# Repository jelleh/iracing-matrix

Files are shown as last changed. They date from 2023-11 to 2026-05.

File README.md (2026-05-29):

# iRacing Matrix

## Description

Arduino based low latency RPM and gear indicator for the iRacing motorsport simulator.  

## Overview

The goal is to build a plug-and-race, easy to setup, low latency gear and RPM indicator for iRacing.  

It will display your current speed and RPM on the 7 segment display  
On the left led strip you will see the braking percentage,  
and the right strip displays the RPM percentage between 70% and 100%  
The RPM led strip will blink quickly when the RPM percentage is above 99%  
  
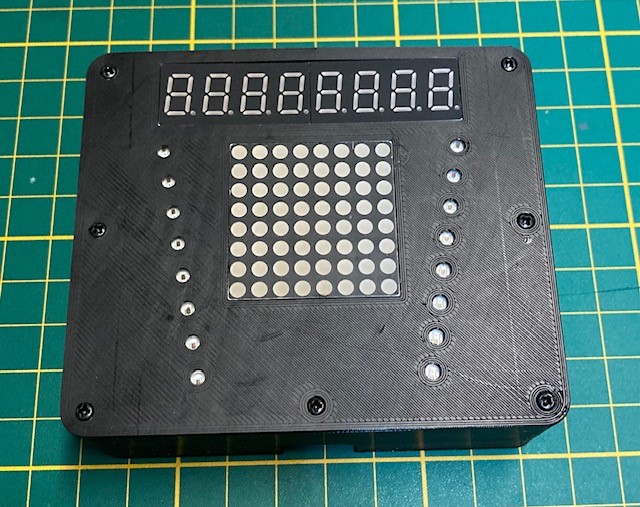
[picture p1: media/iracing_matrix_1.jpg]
  
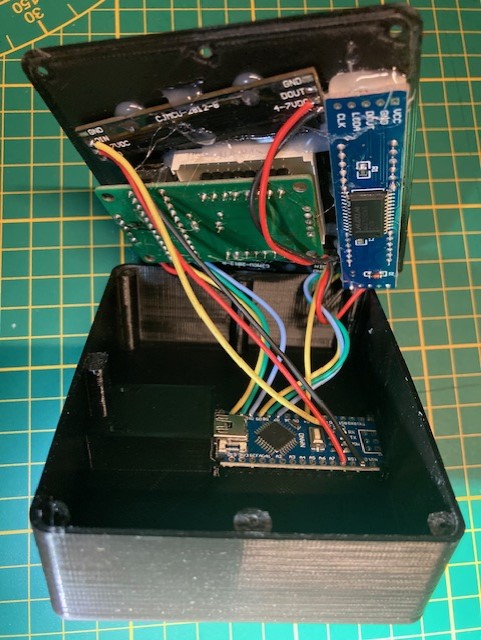
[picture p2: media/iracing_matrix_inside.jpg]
Housing inside
  
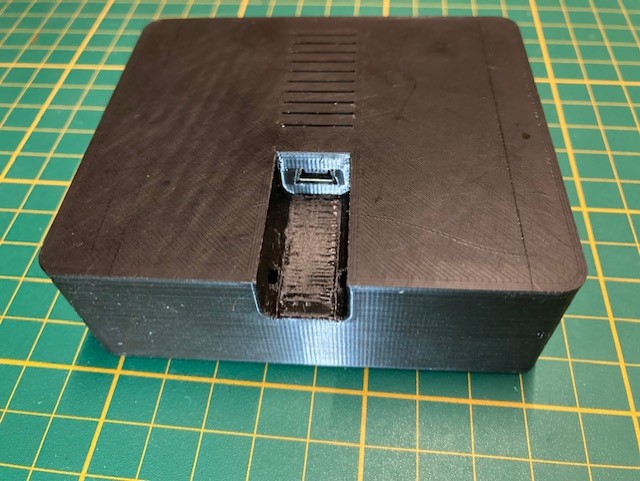
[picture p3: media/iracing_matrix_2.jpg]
  
  
>STL files included and available on [Thingiverse](https://www.thingiverse.com/thing:6325240)

*Running the executable*  
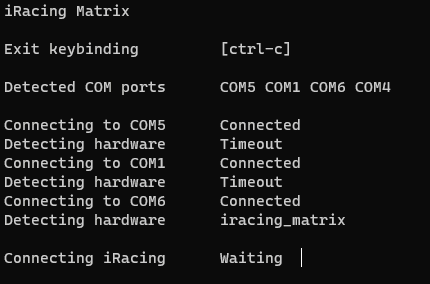
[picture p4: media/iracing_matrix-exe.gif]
Executable


*Calibrate the RPM indicator and drive*  
Calibrate RPM  

*Fast cycle through gears*  
Race  

## Components

To build iRacing Matrix, you will need the following components:  
>You can buy all the components on [AliExpress](https://s.click.aliexpress.com/e/_DcGzUr5).  

1. **Microcontroller Board:**
   - Description: The brain is an Arduino board with mini usb, the Arduino Nano will fit the housing.
   - Example: [Arduino Nano Atmega328 mini usb](https://s.click.aliexpress.com/e/_DkWYniB)

1. **Housing:**
   - Description: The provided housing is build to fit an Arduino nano, feel free to build your own housing.
   - Example: Available in the housing directory or at [Thingiverse](https://www.thingiverse.com/thing:6325240)

2. **Gear indicator:**
   - Description: Gear indicator is a MAX7219 Dot Led Matrix Module
   - Example: [MAX7219 Dot Led Matrix Module](https://s.click.aliexpress.com/e/_Dli12on)

3. **RPM and brake indicator:**
   - Description: RPM and brake indicator are two 8 channel WS2812 505 RGB LED strips
   - Example: [WS2812 5050 8 channel RGB LED](https://s.click.aliexpress.com/e/_DlZAn4x)

4. **Display:**
   - Description: MAX7219 based 8 digits 7 segments display
   - Example: [MAX7219 8 digits 7 segments](https://s.click.aliexpress.com/e/_Dewr8uB)

6. **Screws, Wires and hot glue:**
   - Description: Used for assembling and connecting components.
   - Example:
     - [Silicone 28AWG wires](https://s.click.aliexpress.com/e/_Dm14y7V)
     - [M1.7x6 screws](https://s.click.aliexpress.com/e/_DB2Fljt)
     - [Hot glue gun](https://s.click.aliexpress.com/e/_DlX8qxz)

## Schematic

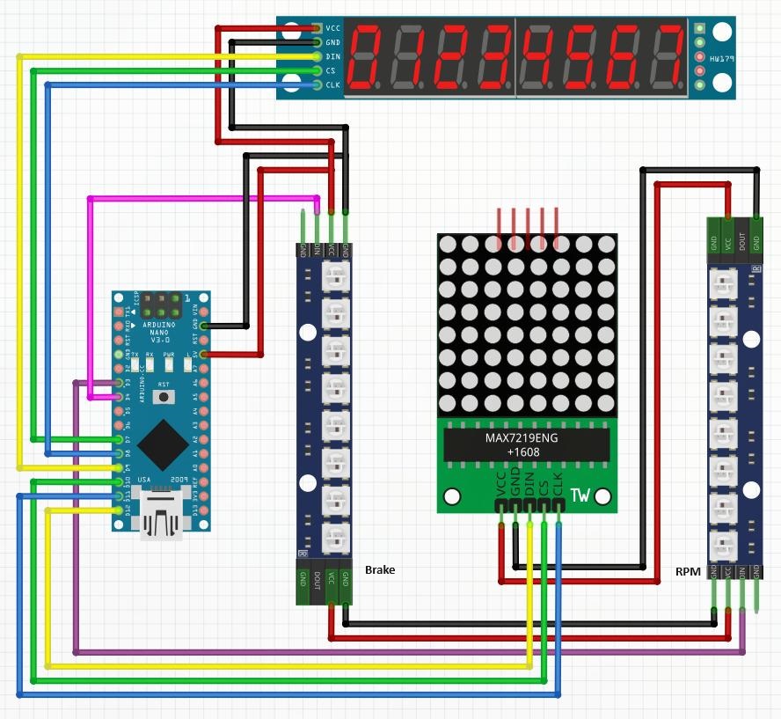
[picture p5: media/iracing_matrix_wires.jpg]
Wires


## Housing

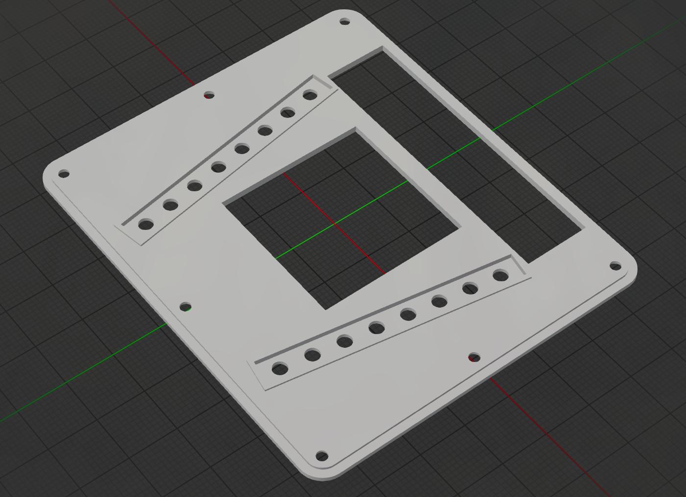
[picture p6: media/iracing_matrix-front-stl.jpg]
Housing front

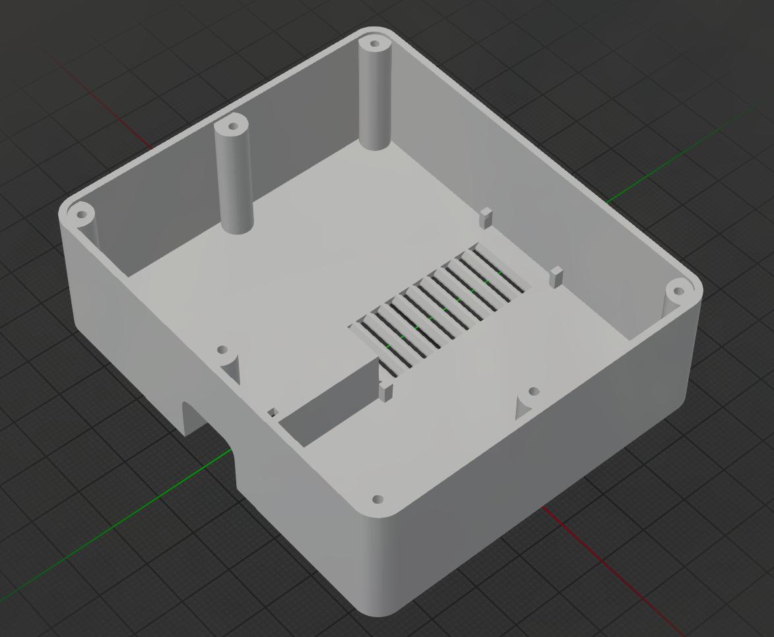
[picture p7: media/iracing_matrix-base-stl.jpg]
Housing base
  
Download on [Thingiverse](https://www.thingiverse.com/thing:6325240/files)  

## Building from source

Requires [MinGW-w64](https://www.mingw-w64.org/) (cross-compile on Linux) or Visual Studio (on Windows).

**VS Code (Linux):** open the repo, then **Terminal → Run Build Task** — this runs the MinGW-w64 cross-compiler and outputs `iracing_matrix.exe`.

**CLI (Linux):**
```bash
cd program/iracing_matrix
x86_64-w64-mingw32-g++ -o iracing_matrix.exe iracing_matrix.cpp irsdk/irsdk_client.cpp irsdk/irsdk_utils.cpp irsdk/yaml_parser.cpp irsdk/irsdk_ir2ad/serial.cpp -I irsdk -I irsdk/irsdk_ir2ad -lwinmm -static -O2
```

**Visual Studio (Windows):** open `program/iracing_matrix.sln` and build.

## Executable

Download the prebuild [iracing_matrix.exe](https://github.com/jelleh/iracing-matrix/releases/download/v1.0/iracing_matrix.exe), or build it from source with Visual Studio.  
The executable will interact with the iracing API, and send updates over the COM port to the Arduino.  
When started, it will scan all the available COM ports for the iRacing Matrix,  
You can provide a fixed COM in the paramaters for faster startup.  
> iracing_matrix.exe [COM port]  
> e.g.: *iracing_matrix.exe 5*  

## Calibration
The RPM indicator needs to be calibrated once per session.  
When calibration is needed, iRacing Matrix will display *fll thr* on the 7-segment digits.  
Completely stop the car, enter neutral gear, and full throtle.  

## Getting Started

Follow these steps to build and use iRacing Matrix:

1. **Assemble iRacing Matrix:**
   - Connect the microcontroller to your computer and upload the provided Arduino code [iracing_matrix.ino](sketch/iracing_matrix/iracing_matrix.ino).
   - Remove the sides (mounting holes) from the 7-segment display with a hacksaw, otherwise it will not fit. (see pictures)
   - Follow the circuit diagram to connect the components to the microcontroller.
   - Download the [stl files](./housing), and print the housing.
   - Glue the components to the front part of the housing with some hot glue.
   - Secure the Arduino nano in the housing, first put the mini usb in the opening, and push the Arduino all the way down.
   - Attach the front and base toghther with seven M1.7x6 screws.

2. **Connect:**
   - Connect the Arduino via usb to you computer.

3. **Run:**
   - Run [iracing_matrix.exe](https://github.com/jelleh/iracing-matrix/releases/download/v1.0/iracing_matrix.exe) on your iRacing pc. It will automiticly scan the COM ports for iRacing Matrix.

4. **Calibrate:**
   - Enter an iRacing session, and full throtle in netrual gear to calibrate the RPM indicator.

5. **Race:**
   - Exit the pit, and race.

## License

This project is licensed under the [BSD-3-Clause](LICENSE).

---

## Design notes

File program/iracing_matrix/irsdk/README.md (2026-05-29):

irsdk
=====

Clone of the offical iRacing SDK C++ library

====

The following is from the iRacing members forum: http://members.iracing.com/jforum/posts/list/1470675.page

Welcome to the new iRacing SDK, this api replaces the original iRacing Telemetry API with a cleaner implementation that supports multiple clients and an expanded list of functions. 

history: 
2011/04/27 - initial release 

2011/05/03 - Maintenance update 
- Fixed a conflict between Windows UAC and live telemetry, applications will need to be recompiled to continue working. 
- Fixed a bug in irsdk_broadcastMsg() that could cause the caller to hang indefinitely. 
- Telemetry now properly output from a replay 
- Removed the CarIdxThrottlePct, CarIdxBrakePct, and CarIdxClutchPct variables. 
- Fixed a bug that caused camera data to be erratic when pausing the simulator. 
- Added a small sample demonstrating how to read in an ibt file and convert it to a csv file. 

2011/05/06 - Maintenance update 
- Fixed a bug in the YAML parser that would not parse numbers greater than 9 in array entries {} 
- Initial stub of a C# port, probably not worth looking at. 

2013/01/15 - Maintenance update 
- Added new remote call 'irsdk_BroadcastReloadTextures' to trigger a reload of custom car textures. 

2013/07/22 - Maintenance update 
- Added new remote call 'irsdk_BroadcastChatComand' to help automate chat commands. 
- Added new remote call 'irsdk_BroadcastPitCommand' to allow custom manipulation of pit stop settings. 

2014/04/23 - Maintenance update
- Added new remote call 'irsdk_BroadcastTelemCommand' to allow toggling on/off of disk based telemetry 

2015/09/23 - Maintenance update
- Add new telemetry defines to irsdk_defines.h

2016/04/19 - Maintenance update
- New irsdkDiskClient helper class to simplify reading disk based .ibt files
- New irsdk_ffbforce demo that uses above class to monitor force feedback steering torque

2016/12/06 - Maintenance update
- Add support for 360 Hz telemetry
- New csvt2ibt project that converts csv text files to .ibt files 

2017/04/14 - Maintenance update
- clean up build scripts for VC2012 compatibility

2017/04/21 - Maintenance update
- improve csv2ibt so it can import csv files produced by writetest 

2019/01/26 - Maintenance update
- Update to SDK Version 1.12 and 
- Update of Windows SDK and VC platform toolset

2020/12/31 - Maintenance update
- Update of project files to VS2019

2021/05/21 - Maintenance update, added message support for control over video recording and screenshots.  

2024/03/04 - New rain defines, new .ibt irsdkDiskWriter class.  

2024/03/06 - New rain defines  

2024/03/18 - New tire compound change enum

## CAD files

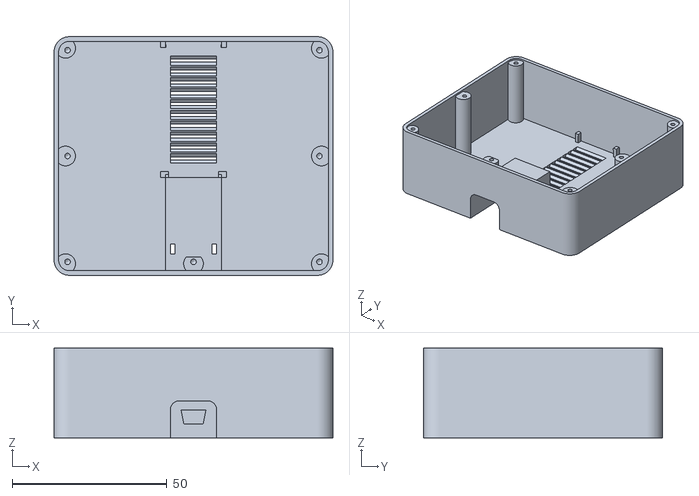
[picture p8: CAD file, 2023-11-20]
housing/iracing_matrix-base.stl
90.0 x 77.0 x 29.0

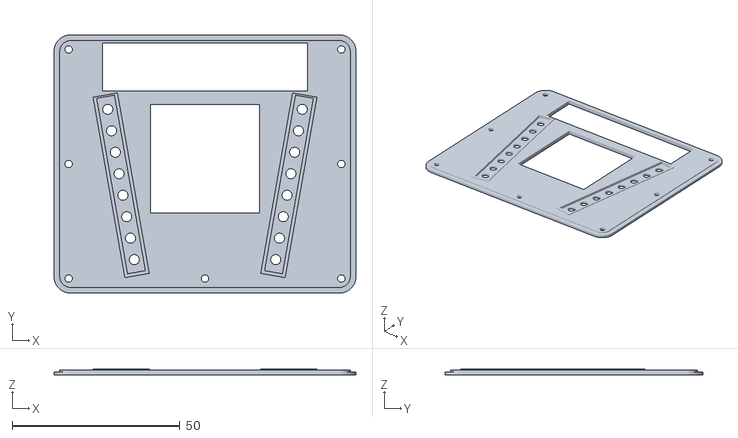
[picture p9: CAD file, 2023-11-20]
housing/iracing_matrix-front.stl
90.0 x 77.0 x 1.90

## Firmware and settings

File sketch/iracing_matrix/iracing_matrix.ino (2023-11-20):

/*
# Copyright (c) 2023 Jelle Hennevelt <jelle_AT_hennevelt_DOT_nl>
#
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
# 3. Neither the name of the copyright holder nor the names of its
# contributors may be used to endorse or promote products derived from this
# software without specific prior written permission.
#
# THIS SOFTWARE IS PROVIDED BY THE COPYRIGHT HOLDERS AND CONTRIBUTORS "AS
# IS" AND ANY EXPRESS OR IMPLIED WARRANTIES, INCLUDING, BUT NOT LIMITED TO,
# THE IMPLIED WARRANTIES OF MERCHANTABILITY AND FITNESS FOR A PARTICULAR
# PURPOSE ARE DISCLAIMED. IN NO EVENT SHALL THE COPYRIGHT HOLDER OR
# CONTRIBUTORS BE LIABLE FOR ANY DIRECT, INDIRECT, INCIDENTAL, SPECIAL,
# EXEMPLARY, OR CONSEQUENTIAL DAMAGES (INCLUDING, BUT NOT LIMITED TO,
# PROCUREMENT OF SUBSTITUTE GOODS OR SERVICES; LOSS OF USE, DATA, OR PROFITS;
# OR BUSINESS INTERRUPTION) HOWEVER CAUSED AND ON ANY THEORY OF LIABILITY,
# WHETHER IN CONTRACT, STRICT LIABILITY, OR TORT (INCLUDING NEGLIGENCE OR
# OTHERWISE) ARISING IN ANY WAY OUT OF THE USE OF THIS SOFTWARE,
# EVEN IF ADVISED OF THE POSSIBILITY OF SUCH DAMAGE.

# SPDX-License-Identifier: BSD-3-Clause
*/

#include "LedControl.h"
#include <Adafruit_NeoPixel.h>

// LED Matrix pins (DIN, CLK, LOAD/CS, MaxID)
// pin 12 is connected to DIN
// pin 11 is connected to CLK
// pin 10 is connected to LOAD/CS
LedControl lcMatrix=LedControl(12,11,10,1);

// pin 9 is connected to DIN
// pin 8 is connected to CLK
// pin 7 is connected to LOAD/CS
LedControl lcDigit=LedControl(9,8,7,1);

#define stripRpmPIN 3
#define stripBrakePIN 4
Adafruit_NeoPixel stripRpm = Adafruit_NeoPixel(8, stripRpmPIN, NEO_GRB + NEO_KHZ800);
Adafruit_NeoPixel stripBrake = Adafruit_NeoPixel(8, stripBrakePIN, NEO_GRB + NEO_KHZ800);


int maxRPM=0;
int lastRPM=0;
int lastGEAR=0;
//int rnd=0;

float lastSPEED=0;
float lastBRAKE=0;

String myString;
String type;

bool startRead=false;
bool stopRead=false;
byte matrixDC[8] = { B10000001,B01000010,B00100100,B00011000,B00011000,B00100100,B01000010,B10000001 };
byte matrixC[8] = { B00111100,B01100010,B01100000,B01100000,B01100000,B01100000,B01100010,B00111100 };
byte matrixR[8] = { B00111100,B01100110,B01100110,B01100100,B01111000,B01111000,B01101100,B01100110 };
byte matrixN[8] = { B01100110,B01100110,B01110110,B01111110,B01101110,B01100110,B01100110,B01100110 };
byte matrix1[8] = { B00011000,B00111000,B00011000,B00011000,B00011000,B00011000,B00011000,B01111110 };
byte matrix2[8] = { B00111100,B01100110,B00000110,B00001100,B00011000,B00110000,B01111110,B01111110 };
byte matrix3[8] = { B00111100,B01100110,B00000110,B00001100,B00001100,B00000110,B01100110,B00111100 };
byte matrix4[8] = { B00000110,B00001110,B00010110,B00100110,B01100110,B01111111,B00000110,B00000110 };
byte matrix5[8] = { B01111110,B01100000,B01100000,B01111100,B00000110,B00000110,B01100110,B00111100 };
byte matrix6[8] = { B00111100,B01100110,B01100000,B01111100,B01111110,B01100110,B01100110,B00111100 };
byte matrix7[8] = { B01111110,B01000110,B00000110,B00001100,B00001100,B00011000,B00011000,B00011000 };
byte matrix8[8] = { B00111100,B01100110,B01100110,B01111110,B01111110,B01100110,B01100110,B00111100 };
int row;

uint32_t rpmGREEN = stripRpm.Color(128, 255, 0);
uint32_t rpmYELLOW = stripRpm.Color(255, 166, 0);
uint32_t rpmRED = stripRpm.Color(255, 0, 0);
uint32_t rpmOFF = stripRpm.Color(0, 0, 0);
uint32_t rpmBlinkMillis = millis();
uint16_t rpmBlinkDelay = 50;

uint32_t brakeGREEN = stripRpm.Color(128, 255, 0);
uint32_t brakeYELLOW = stripRpm.Color(255, 166, 0);
uint32_t brakeRED = stripRpm.Color(255, 0, 0);
uint32_t brakeOFF = stripRpm.Color(0, 0, 0);

uint32_t dataRXmillis = millis();
uint16_t dataRXth = 1000;
uint32_t dataTXmillis = millis();

bool dataRX = false;

uint8_t toggle=0;


void setup()
{
  Serial.begin(115200);
  myString.reserve(200);

  //RPM Strip
  stripRpm.begin();
  stripRpm.setBrightness(20);
  for(int i=0; i<stripRpm.numPixels(); i++) {
    stripRpm.setPixelColor(i, rpmOFF);
  }
  stripRpm.show();

  //Brake Strip
  stripBrake.begin();
  stripBrake.setBrightness(20);
  for(int i=0; i<stripBrake.numPixels(); i++) {
    stripBrake.setPixelColor(i, brakeOFF);
  }
  stripBrake.show();

  //Gear Matrix
  lcMatrix.shutdown(0,false);// enables display
  lcMatrix.setIntensity(0,5);// sets brightness (0~15 possible values)
  lcMatrix.clearDisplay(0);// clear screen

  //RPM/SPEED Digits
  lcDigit.shutdown(0,false);// enables display
  lcDigit.setIntensity(0,5);// sets brightness (0~15 possible values)
  lcDigit.clearDisplay(0);// clear screen
}


void resetRPM()
{
  lcDigit.setRow(0,7,0x47);
  lcDigit.setRow(0,6,0x1c);
  lcDigit.setRow(0,5,0x0E);
  lcDigit.setRow(0,4,0x0E);
  lcDigit.setChar(0,3,' ',false);
  lcDigit.setRow(0,2,0x0F);
  lcDigit.setRow(0,1,0x17);
  lcDigit.setRow(0,0,0x05);

  //lcDigit.setChar(0,7,'f',false);
  //lcDigit.setRow(0,6,0x1c);
  //lcDigit.setChar(0,5,'l',false);
  //lcDigit.setChar(0,4,'l',false);
  //lcDigit.setChar(0,3,' ',false);
  //lcDigit.setRow(0,2,0x05);
  //lcDigit.setChar(0,1,'p',false);
  //lcDigit.setRow(0,0,0x15);
}


void lcdReady(bool sim=false)
{
  if(sim){
    lcDigit.setRow(0,7,0x05);
    lcDigit.setRow(0,6,0x3D);
    lcDigit.setRow(0,5,0x3B);
    lcDigit.setChar(0,4,' ',false);
    lcDigit.setChar(0,3,' ',false);
    lcDigit.setRow(0,2,0x05);
    lcDigit.setRow(0,1,0x3D);
    lcDigit.setRow(0,0,0x3B);  
  } else {
    lcDigit.setRow(0,7,0x05);
    lcDigit.setRow(0,6,0x3D);
    lcDigit.setRow(0,5,0x3B);
    lcDigit.setChar(0,4,' ',false);
    lcDigit.setChar(0,3,' ',false);
    lcDigit.setChar(0,2,' ',false);
    lcDigit.setChar(0,1,' ',false);
    lcDigit.setChar(0,0,' ',false);
  }
}


void rpmDigit(int value=0)
{
  int ones;
  int tens;
  int hundreds;
  int thousands;

  if(value < 10000){
    ones=value%10;
    value=value/10;
    tens=value%10;
    value=value/10;
    hundreds=value%10;
    value=value/10;
    thousands=value;

    lcDigit.setDigit(0,3,(byte)thousands,false);
    lcDigit.setDigit(0,2,(byte)hundreds,false);
    lcDigit.setDigit(0,1,(byte)tens,false);
    lcDigit.setDigit(0,0,(byte)ones,false);
  } 
  else{
    lcDigit.setDigit(0,3,(byte)9,false);
    lcDigit.setDigit(0,2,(byte)9,false);
    lcDigit.setDigit(0,1,(byte)9,false);
    lcDigit.setDigit(0,0,(byte)9,false);
  }
}


void speedDigit(int value=0)
{
  int ones;
  int tens;
  int hundreds;

  if(value < 1000){
    ones=value%10;
    value=value/10;
    tens=value%10;
    value=value/10;
    hundreds=value%10;
    
    lcDigit.setDigit(0,7,(byte)hundreds,false);
    lcDigit.setDigit(0,6,(byte)tens,false);
    lcDigit.setDigit(0,5,(byte)ones,false);
    lcDigit.setChar(0,4,' ',false);
  } 
  else{
    lcDigit.setDigit(0,7,(byte)9,false);
    lcDigit.setDigit(0,6,(byte)9,false);
    lcDigit.setDigit(0,5,(byte)9,false);
    lcDigit.setChar(0,4,' ',false);
  }
}


void gearMatrix(int value=0)
{         
  switch(value){
    //R
    case -1:
      row = 7;
      for (int column = 0; column < 8; column++) {
        lcMatrix.setColumn(0, column, matrixR[row]);
        row--;
      }
      break;

    //N  
    case 0:
      row = 7;
      for (int column = 0; column < 8; column++) {
        lcMatrix.setColumn(0, column, matrixN[row]);
        row--;
      }
      break;

    //1
    case 1:
      row = 7;
      for (int column = 0; column < 8; column++) {
        lcMatrix.setColumn(0, column, matrix1[row]);
        row--;
      }
      break;

    //2  
    case 2:
      row = 7;
      for (int column = 0; column < 8; column++) {
        lcMatrix.setColumn(0, column, matrix2[row]);
        row--;
      }
      break;

    //3  
    case 3:
      row = 7;
      for (int column = 0; column < 8; column++) {
        lcMatrix.setColumn(0, column, matrix3[row]);
        row--;
      }
      break;

    //4  
    case 4:
      row = 7;
      for (int column = 0; column < 8; column++) {
        lcMatrix.setColumn(0, column, matrix4[row]);
        row--;
      }
      break;

    //5  
    case 5:
      row = 7;
      for (int column = 0; column < 8; column++) {
        lcMatrix.setColumn(0, column, matrix5[row]);
        row--;
      }
      break;

    //6
    case 6:
      row = 7;
      for (int column = 0; column < 8; column++) {
        lcMatrix.setColumn(0, column, matrix6[row]);
        row--;
      }
      break;

    //7
    case 7:
      row = 7;
      for (int column = 0; column < 8; column++) {
        lcMatrix.setColumn(0, column, matrix7[row]);
        row--;
      }         
      break;

    //8
    case 8:
      row = 7;
      for (int column = 0; column < 8; column++) {
        lcMatrix.setColumn(0, column, matrix8[row]);
        row--;
      }    
      break;

    //C
    case 98:
      row = 7;
      for (int column = 0; column < 8; column++) {
        lcMatrix.setColumn(0, column, matrixC[row]);
        row--;
      }
      break;

    //X
    case 99:
      row = 7;
      for (int column = 0; column < 8; column++) {
        lcMatrix.setColumn(0, column, matrixDC[row]);
        row--;
      }
      break;
  }
}

void rpmStrip(int value=0, int brightness=25)
{
  if (brightness < 16){ brightness = 16; }
  if (brightness > 255){ brightness = 255; }

  if (value == -1){
    toggle = ~toggle;    
    if (toggle)
    {
      stripRpm.setBrightness(brightness);
      //for(int i=0; i<stripRpm.numPixels(); i++) {
      for(int i=stripRpm.numPixels(); i>=0; i--) {
        stripRpm.setPixelColor(i, rpmRED);
      }
      stripRpm.show();
    }else{
      stripRpm.setBrightness(brightness-10);
      for(int i=0; i<stripRpm.numPixels(); i++) {
        stripRpm.setPixelColor(i, rpmRED);
      }
      stripRpm.show();
    }
  } else if (value > ((maxRPM / 100) * 99))
  {

    toggle = ~toggle;    
    if (toggle)
    {
      if ((millis()-rpmBlinkMillis) > rpmBlinkDelay){
        rpmBlinkMillis=millis();
        //rnd=1;
        stripRpm.setBrightness(brightness);
        //for(int i=0; i<stripRpm.numPixels(); i++) {
        for(int i=stripRpm.numPixels(); i>=0; i--) {
          stripRpm.setPixelColor(i, rpmRED);
        }
        stripRpm.show();
      }
    }else{
      if ((millis()-rpmBlinkMillis) > rpmBlinkDelay){
        rpmBlinkMillis=millis();
        //rnd=0;
        stripRpm.setBrightness(brightness);
        //for(int i=0; i<stripRpm.numPixels(); i++) {
        for(int i=stripRpm.numPixels(); i>=0; i--) {
          stripRpm.setPixelColor(i, rpmOFF);
        }
        stripRpm.show();
      }
    }
  }
  //8
  else if (value > ((maxRPM / 100) * 98))
  { 
    stripRpm.setBrightness(brightness-5);
    stripRpm.setPixelColor(0, rpmGREEN);
    stripRpm.setPixelColor(1, rpmGREEN);
    stripRpm.setPixelColor(2, rpmGREEN);
    stripRpm.setPixelColor(3, rpmYELLOW);
    stripRpm.setPixelColor(4, rpmYELLOW);
    stripRpm.setPixelColor(5, rpmYELLOW);
    stripRpm.setPixelColor(6, rpmRED);
    stripRpm.setPixelColor(7, rpmRED);
    stripRpm.show();
  }
  //7
  else if (value > ((maxRPM / 100) * 96))
  {
    stripRpm.setBrightness(brightness-5);
    stripRpm.setPixelColor(0, rpmGREEN);
    stripRpm.setPixelColor(1, rpmGREEN);
    stripRpm.setPixelColor(2, rpmGREEN);
    stripRpm.setPixelColor(3, rpmYELLOW);
    stripRpm.setPixelColor(4, rpmYELLOW);
    stripRpm.setPixelColor(5, rpmYELLOW);
    stripRpm.setPixelColor(6, rpmRED);
    stripRpm.setPixelColor(7, rpmOFF);
    stripRpm.show();
  }
  //6
  else if (value > ((maxRPM / 100) * 94))
  {   
    stripRpm.setBrightness(brightness-5);
    stripRpm.setPixelColor(0, rpmGREEN);
    stripRpm.setPixelColor(1, rpmGREEN);
    stripRpm.setPixelColor(2, rpmGREEN);
    stripRpm.setPixelColor(3, rpmYELLOW);
    stripRpm.setPixelColor(4, rpmYELLOW);
    stripRpm.setPixelColor(5, rpmYELLOW);
    stripRpm.setPixelColor(6, rpmOFF);
    stripRpm.setPixelColor(7, rpmOFF);
    stripRpm.show(); 
  }
  //5
  else if (value > ((maxRPM / 100) * 92))
  {
    stripRpm.setBrightness(brightness-7);
    stripRpm.setPixelColor(0, rpmGREEN);
    stripRpm.setPixelColor(1, rpmGREEN);
    stripRpm.setPixelColor(2, rpmGREEN);
    stripRpm.setPixelColor(3, rpmYELLOW);
    stripRpm.setPixelColor(4, rpmYELLOW);
    stripRpm.setPixelColor(5, rpmOFF);
    stripRpm.setPixelColor(6, rpmOFF);
    stripRpm.setPixelColor(7, rpmOFF);
    stripRpm.show();
  }
  //4
  else if (value > ((maxRPM / 100) * 90))
  {
    stripRpm.setBrightness(brightness-9);
    stripRpm.setPixelColor(0, rpmGREEN);
    stripRpm.setPixelColor(1, rpmGREEN);
    stripRpm.setPixelColor(2, rpmGREEN);
    stripRpm.setPixelColor(3, rpmYELLOW);
    stripRpm.setPixelColor(4, rpmOFF);
    stripRpm.setPixelColor(5, rpmOFF);
    stripRpm.setPixelColor(6, rpmOFF);
    stripRpm.setPixelColor(7, rpmOFF);
    stripRpm.show();
  }
  //3
  else if (value > ((maxRPM / 100) * 85))
  {    
    stripRpm.setBrightness(brightness-11);
    stripRpm.setPixelColor(0, rpmGREEN);
    stripRpm.setPixelColor(1, rpmGREEN);
    stripRpm.setPixelColor(2, rpmGREEN);
    stripRpm.setPixelColor(3, rpmOFF);
    stripRpm.setPixelColor(4, rpmOFF);
    stripRpm.setPixelColor(5, rpmOFF);
    stripRpm.setPixelColor(6, rpmOFF);
    stripRpm.setPixelColor(7, rpmOFF);
    stripRpm.show();
  }
  //2
  else if (value > ((maxRPM / 100) * 80))
  {
    stripRpm.setBrightness(brightness-13);
    stripRpm.setPixelColor(0, rpmGREEN);
    stripRpm.setPixelColor(1, rpmGREEN);
    stripRpm.setPixelColor(2, rpmOFF);
    stripRpm.setPixelColor(3, rpmOFF);
    stripRpm.setPixelColor(4, rpmOFF);
    stripRpm.setPixelColor(5, rpmOFF);
    stripRpm.setPixelColor(6, rpmOFF);
    stripRpm.setPixelColor(7, rpmOFF);
    stripRpm.show();
  }
  //1
  else if (value > ((maxRPM / 100) * 70))
  {  
    stripRpm.setBrightness(brightness-15);
    stripRpm.setPixelColor(0, rpmGREEN);
    stripRpm.setPixelColor(1, rpmOFF);
    stripRpm.setPixelColor(2, rpmOFF);
    stripRpm.setPixelColor(3, rpmOFF);
    stripRpm.setPixelColor(4, rpmOFF);
    stripRpm.setPixelColor(5, rpmOFF);
    stripRpm.setPixelColor(6, rpmOFF);
    stripRpm.setPixelColor(7, rpmOFF);
    stripRpm.show();
  }
  //0
  else if (value < ((maxRPM / 100) * 70))
  {
    brightness = 1;
      
    stripRpm.setBrightness(brightness);
    //for(int i=0; i<stripRpm.numPixels(); i++) {
    for(int i=stripRpm.numPixels(); i>=0; i--) {
      stripRpm.setPixelColor(i, rpmOFF);
    }
    stripRpm.show();
  }
}


void brakeStrip(float value=0, int brightness=25)
{
  if (brightness < 21){ brightness = 21; }
  if (brightness > 255){ brightness = 255; }

  float maxBRAKE=1.0;

  if (value == -1){
    toggle = ~toggle;    
    if (toggle)
    {
      stripBrake.setBrightness(brightness-10);
      for(int i=0; i<stripBrake.numPixels(); i++) {
        stripBrake.setPixelColor(i, brakeRED);
      }
      stripBrake.show();
    }else{
      stripBrake.setBrightness(brightness);
      for(int i=0; i<stripBrake.numPixels(); i++) {
        stripBrake.setPixelColor(i, brakeRED);
      }
      stripBrake.show();
    }
  }else if (value > ((maxBRAKE / 100) * 96))
  {
    stripBrake.setBrightness(brightness);
    stripBrake.setPixelColor(7, brakeGREEN);
    stripBrake.setPixelColor(6, brakeGREEN);
    stripBrake.setPixelColor(5, brakeGREEN);
    stripBrake.setPixelColor(4, brakeYELLOW);
    stripBrake.setPixelColor(3, brakeYELLOW);
    stripBrake.setPixelColor(2, brakeYELLOW);
    stripBrake.setPixelColor(1, brakeRED);
    stripBrake.setPixelColor(0, brakeRED);
    stripBrake.show();
  }
  else if (value > ((maxBRAKE / 100) * 84))
  {
    stripBrake.setBrightness(brightness-10);
    stripBrake.setPixelColor(7, brakeGREEN);
    stripBrake.setPixelColor(6, brakeGREEN);
    stripBrake.setPixelColor(5, brakeGREEN);
    stripBrake.setPixelColor(4, brakeYELLOW);
    stripBrake.setPixelColor(3, brakeYELLOW);
    stripBrake.setPixelColor(2, brakeYELLOW);
    stripBrake.setPixelColor(1, brakeRED);
    stripBrake.setPixelColor(0, brakeRED);
    stripBrake.show();
  }
  else if (value > ((maxBRAKE / 100) * 72))
  {
    stripBrake.setBrightness(brightness-12);
    stripBrake.setPixelColor(7, brakeGREEN);
    stripBrake.setPixelColor(6, brakeGREEN);
    stripBrake.setPixelColor(5, brakeGREEN);
    stripBrake.setPixelColor(4, brakeYELLOW);
    stripBrake.setPixelColor(3, brakeYELLOW);
    stripBrake.setPixelColor(2, brakeYELLOW);
    stripBrake.setPixelColor(1, brakeRED);
    stripBrake.setPixelColor(0, brakeOFF);
    stripBrake.show();
  }
  else if (value > ((maxBRAKE / 100) * 60))
  {
    stripBrake.setBrightness(brightness-14);
    stripBrake.setPixelColor(7, brakeGREEN);
    stripBrake.setPixelColor(6, brakeGREEN);
    stripBrake.setPixelColor(5, brakeGREEN);
    stripBrake.setPixelColor(4, brakeYELLOW);
    stripBrake.setPixelColor(3, brakeYELLOW);
    stripBrake.setPixelColor(2, brakeYELLOW);
    stripBrake.setPixelColor(1, brakeOFF);
    stripBrake.setPixelColor(0, brakeOFF);
    stripBrake.show();
  }
  else if (value > ((maxBRAKE / 100) * 48))
  {
    stripBrake.setBrightness(brightness-16);
    stripBrake.setPixelColor(7, brakeGREEN);
    stripBrake.setPixelColor(6, brakeGREEN);
    stripBrake.setPixelColor(5, brakeGREEN);
    stripBrake.setPixelColor(4, brakeYELLOW);
    stripBrake.setPixelColor(3, brakeYELLOW);
    stripBrake.setPixelColor(2, brakeOFF);
    stripBrake.setPixelColor(1, brakeOFF);
    stripBrake.setPixelColor(0, brakeOFF);
    stripBrake.show();
  }
  else if (value > ((maxBRAKE / 100) * 36))
  {
    stripBrake.setBrightness(brightness-17);
    stripBrake.setPixelColor(7, brakeGREEN);
    stripBrake.setPixelColor(6, brakeGREEN);
    stripBrake.setPixelColor(5, brakeGREEN);
    stripBrake.setPixelColor(4, brakeYELLOW);
    stripBrake.setPixelColor(3, brakeOFF);
    stripBrake.setPixelColor(2, brakeOFF);
    stripBrake.setPixelColor(1, brakeOFF);
    stripBrake.setPixelColor(0, brakeOFF);
    stripBrake.show();
  }
  else if (value > ((maxBRAKE / 100) * 24))
  {
    stripBrake.setBrightness(brightness-18);
    stripBrake.setPixelColor(7, brakeGREEN);
    stripBrake.setPixelColor(6, brakeGREEN);
    stripBrake.setPixelColor(5, brakeGREEN);
    stripBrake.setPixelColor(4, brakeOFF);
    stripBrake.setPixelColor(3, brakeOFF);
    stripBrake.setPixelColor(2, brakeOFF);
    stripBrake.setPixelColor(1, brakeOFF);
    stripBrake.setPixelColor(0, brakeOFF);
    stripBrake.show();
  }
  else if (value > ((maxBRAKE / 100) * 12))
  {
    stripBrake.setBrightness(brightness-19);
    stripBrake.setPixelColor(7, brakeGREEN);
    stripBrake.setPixelColor(6, brakeGREEN);
    stripBrake.setPixelColor(5, brakeOFF);
    stripBrake.setPixelColor(4, brakeOFF);
    stripBrake.setPixelColor(3, brakeOFF);
    stripBrake.setPixelColor(2, brakeOFF);
    stripBrake.setPixelColor(1, brakeOFF);
    stripBrake.setPixelColor(0, brakeOFF);
    stripBrake.show();
  }
  else if (value > ((maxBRAKE / 100) * 0))
  {
    stripBrake.setBrightness(brightness-20);
    stripBrake.setPixelColor(7, brakeGREEN);
    stripBrake.setPixelColor(6, brakeOFF);
    stripBrake.setPixelColor(5, brakeOFF);
    stripBrake.setPixelColor(4, brakeOFF);
    stripBrake.setPixelColor(3, brakeOFF);
    stripBrake.setPixelColor(2, brakeOFF);
    stripBrake.setPixelColor(1, brakeOFF);
    stripBrake.setPixelColor(0, brakeOFF);
    stripBrake.show();
  }
  else if (value < ((maxBRAKE / 100) * 1))
  {
    brightness = 1;
    
    stripBrake.setBrightness(brightness);
    for(int i=0; i<stripBrake.numPixels(); i++) {
      stripBrake.setPixelColor(i, brakeOFF);
    }
    stripBrake.show();
  }
}


void clearall(bool reset=false)
{
    if(reset)  
      maxRPM=0;
    
    lcDigit.clearDisplay(0);
    lcMatrix.clearDisplay(0);

    for(int i=0; i<stripBrake.numPixels(); i++) {
      stripBrake.setPixelColor(i, brakeOFF);
    }   
    stripBrake.show();

    for(int i=0; i<stripRpm.numPixels(); i++) {
      stripRpm.setPixelColor(i, rpmOFF);
    }   
    stripRpm.show();
}
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
void loop()
{
  if ((millis()-dataRXmillis) > dataRXth){
    dataRX = false;
  }

  if (dataRX == false) {
    if ((millis()-dataTXmillis) > 1000){
      dataTXmillis=millis();
      noDATA();
      Serial.print("iracing_matrix");
    }
  }

  if (stopRead){
    int mps;
    double kph;
    double mph;
    
    stopRead=false;
    
    if (myString != ""){
      switch(type[0]){
        case 'B':
          lastBRAKE = myString.toFloat();
          brakeStrip(lastBRAKE);
          break;

        case 'G':
          lastGEAR = myString.toInt();
          gearMatrix(lastGEAR);
          break;

        case 'R': 
          lastRPM = myString.toInt();

          if (lastGEAR == 0 && lastSPEED < 10)
          {
            if (lastRPM > maxRPM)
              maxRPM = lastRPM;
          }

          if (maxRPM < 5000)
          {
            resetRPM();
          }
          else
          {
            rpmDigit(lastRPM);
            rpmStrip(lastRPM);
          }
          break;

        case 'S':
          lastSPEED = myString.toFloat();
          mps = myString.toInt();
          kph = lastSPEED * 3.6;
          mph = kph * 5 / 8;

          if (maxRPM < 5000)
          {
            resetRPM();
          }
          else
          {
            speedDigit(kph);
          }     
          break;

        case 'E':
          if (myString.toInt() == 1)
          {
            //Waiting for sim
            clearall(true);
            lcdReady(false);
          }
          else
          {
            //Connected to sim
            clearall(false);
            lcdReady(true);
          }
          break;
      }
    }
  }
}


void serialEvent() 
{
  while (Serial.available()){
    char inChar = (char)Serial.read();
    if (inChar == '!') {
      startRead=true; stopRead=false; myString = "";
      dataRXmillis = millis();
      dataRX = true;
    }else if (inChar == '\n') {
      startRead=false; stopRead=true;
      type = myString[0];
      myString.remove(0,1);
    }else if(startRead){
      myString += inChar;
    }
  }
}

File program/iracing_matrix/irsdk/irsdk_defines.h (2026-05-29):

/*
Copyright (c) 2013, iRacing.com Motorsport Simulations, LLC.
All rights reserved.

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
THIS SOFTWARE IS PROVIDED BY THE COPYRIGHT HOLDERS AND CONTRIBUTORS "AS IS" AND
ANY EXPRESS OR IMPLIED WARRANTIES, INCLUDING, BUT NOT LIMITED TO, THE IMPLIED
WARRANTIES OF MERCHANTABILITY AND FITNESS FOR A PARTICULAR PURPOSE ARE
DISCLAIMED. IN NO EVENT SHALL THE COPYRIGHT OWNER OR CONTRIBUTORS BE LIABLE FOR
ANY DIRECT, INDIRECT, INCIDENTAL, SPECIAL, EXEMPLARY, OR CONSEQUENTIAL DAMAGES
(INCLUDING, BUT NOT LIMITED TO, PROCUREMENT OF SUBSTITUTE GOODS OR SERVICES;
LOSS OF USE, DATA, OR PROFITS; OR BUSINESS INTERRUPTION) HOWEVER CAUSED AND
ON ANY THEORY OF LIABILITY, WHETHER IN CONTRACT, STRICT LIABILITY, OR TORT
(INCLUDING NEGLIGENCE OR OTHERWISE) ARISING IN ANY WAY OUT OF THE USE OF THIS
SOFTWARE, EVEN IF ADVISED OF THE POSSIBILITY OF SUCH DAMAGE.
*/

#ifndef IRSDK_DEFINES_H
#define IRSDK_DEFINES_H

/*
 The IRSDK is a simple api that lets clients access telemetry data from the 
 iRacing simulator. It is broken down into several parts:

 - Live data
   Live data is output from the sim into a shared memory mapped file.  Any
   application can open this memory mapped file and read the telemetry data
   out.  The format of this data was laid out in such a way that it should be
   possible to access from any language that can open a windows memory mapped
   file, without needing an external api.

   There are two different types of data that the telemetry outputs,
   sessionInfo and variables: 
   
   Session info is for data that only needs to be updated every once in a
   while.  This data is output as a YAML formatted string.

   Variables, on the other hand, are output at a rate of 60 times a second.
   The varHeader struct defines each variable that the sim will output, while
   the varData struct gives details about the current line buffer that the vars
   are being written into.  Each variable is packed into a binary array with 
   an offset and length stored in the varHeader.  The number of variables 
   available can change depending on the car or session loaded.  But once the
   sim is running the variable list is locked down and will not change during a
   session.

   The sim writes a new line of variables every 16 ms, and then signals any
   listeners in order to wake them up to read the data.  Because the sim has no
   way of knowing when a listener is done reading the data, we triple buffer
   it in order to give all the clients enough time to read the data out.  This
   gives you a minimum of 16 ms to read the data out and process it.  So it is
   best to copy the data out before processing it.  You can use the function
   irsdk_waitForDataReady() to both wait for new data and copy the data to a
   local buffer.

 - Logged data
   Detailed information about the local drivers car can be logged to disk in
   the form of an ibt binary file.  This logging is enabled in the sim by
   typing alt-L at any time.  The ibt file format directly mirrors the format
   of the live data.

   It is stored as an irsdk_header followed immediately by an irsdk_diskSubHeader.
   After that the offsets in the irsdk_header point to the sessionInfo string, 
   the varHeader, and the varBuffer.

 - Remote Conrol
   You can control the camera selections and playback of a replay tape, from
   any external application by sending a windows message with the 
   irsdk_broadcastMsg() function.
*/

// Constant Definitions

#include <tchar.h>

static const _TCHAR IRSDK_DATAVALIDEVENTNAME[] = _T("Local\\IRSDKDataValidEvent");
static const _TCHAR IRSDK_MEMMAPFILENAME[]     = _T("Local\\IRSDKMemMapFileName");
static const _TCHAR IRSDK_BROADCASTMSGNAME[]   = _T("IRSDK_BROADCASTMSG");

static const int IRSDK_MAX_BUFS = 4;
static const int IRSDK_MAX_STRING = 32;
// descriptions can be longer than max_string!
static const int IRSDK_MAX_DESC = 64; 

// define markers for unlimited session lap and time
static const int IRSDK_UNLIMITED_LAPS = 32767;
static const float IRSDK_UNLIMITED_TIME = 604800.0f;

// latest version of our telemetry headers
static const int IRSDK_VER = 2;

enum irsdk_StatusField
{
	irsdk_stConnected   = 1
};

enum irsdk_VarType
{
	// 1 byte
	irsdk_char = 0,
	irsdk_bool,

	// 4 bytes
	irsdk_int,
	irsdk_bitField,
	irsdk_float,

	// 8 bytes
	irsdk_double,

	//index, don't use
	irsdk_ETCount
};

static const int irsdk_VarTypeBytes[irsdk_ETCount] =
{
	1,		// irsdk_char
	1,		// irsdk_bool

	4,		// irsdk_int
	4,		// irsdk_bitField
	4,		// irsdk_float

	8		// irsdk_double
};

//---

// status 
enum irsdk_TrkLoc
{
	irsdk_NotInWorld = -1,
	irsdk_OffTrack = 0,
	irsdk_InPitStall,
	// This indicates the lead in to pit road, as well as the pit road itself (where speed limits are enforced)
	// if you just want to know that your on the pit road surface look at the live value 'OnPitRoad'
	irsdk_AproachingPits, 
	irsdk_OnTrack
};
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

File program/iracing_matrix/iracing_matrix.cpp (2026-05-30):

/*
# Copyright (c) 2023 Jelle Hennevelt <jelle_AT_hennevelt_DOT_nl>
#
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
# 3. Neither the name of the copyright holder nor the names of its
# contributors may be used to endorse or promote products derived from this
# software without specific prior written permission.
#
# THIS SOFTWARE IS PROVIDED BY THE COPYRIGHT HOLDERS AND CONTRIBUTORS "AS
# IS" AND ANY EXPRESS OR IMPLIED WARRANTIES, INCLUDING, BUT NOT LIMITED TO,
# THE IMPLIED WARRANTIES OF MERCHANTABILITY AND FITNESS FOR A PARTICULAR
# PURPOSE ARE DISCLAIMED. IN NO EVENT SHALL THE COPYRIGHT HOLDER OR
# CONTRIBUTORS BE LIABLE FOR ANY DIRECT, INDIRECT, INCIDENTAL, SPECIAL,
# EXEMPLARY, OR CONSEQUENTIAL DAMAGES (INCLUDING, BUT NOT LIMITED TO,
# PROCUREMENT OF SUBSTITUTE GOODS OR SERVICES; LOSS OF USE, DATA, OR PROFITS;
# OR BUSINESS INTERRUPTION) HOWEVER CAUSED AND ON ANY THEORY OF LIABILITY,
# WHETHER IN CONTRACT, STRICT LIABILITY, OR TORT (INCLUDING NEGLIGENCE OR
# OTHERWISE) ARISING IN ANY WAY OUT OF THE USE OF THIS SOFTWARE,
# EVEN IF ADVISED OF THE POSSIBILITY OF SUCH DAMAGE.

# SPDX-License-Identifier: BSD-3-Clause
*/

// Minimal winver Windows XP
#define MIN_WIN_VER 0x0501

#ifndef WINVER
#	define WINVER			MIN_WIN_VER
#endif

#ifndef _WIN32_WINNT
#	define _WIN32_WINNT		MIN_WIN_VER 
#endif

#pragma warning(disable:4996) //_CRT_SECURE_NO_WARNINGS

#include <windows.h>
#include <cstdint>
#include <conio.h>
#include <signal.h>
#include <string>

#include "irsdk_defines.h"
#include "irsdk_client.h"
#include "yaml_parser.h"
#include "irsdk/irsdk_ir2ad/serial.h"

// for timeBeginPeriod
#pragma comment(lib, "Winmm")


//PitRoad: OnPitRoad == 1 and IsOnTrack == 1
//PitBox: IsInGarage == 0 and IsOnTrack == 0
irsdkCVar g_playerInGarage("IsInGarage");
irsdkCVar g_playerOnPitRoad("OnPitRoad");
irsdkCVar g_playerInCar("IsOnTrack");
irsdkCVar g_pitMaxSpeed("TrackPitSpeedLimit");
irsdkCVar g_carSpeed("Speed");
irsdkCVar g_carRPM("RPM");
irsdkCVar g_carGear("Gear");
irsdkCVar g_carBrake("Brake");



Serial serial;

int comPORT = -1;
bool firstConnect = true;
const char* exeName = "iracing_matrix.exe";
char rxDetect[15] = "iracing_matrix";


void help()
{
	printf("iRacing Matrix usage\n\n%s [port]\n\nport\tEnter COM port number\n", exeName);
	printf("\tLeave empty for auto detect\n\nNote that you can use ctrl-c to exit\n");
	exit(0);
}

void stop(int reset=0)
{
	serial.writeSerialPrintf("!E%i\n", reset);
}

void ex_program(int sig) 
{
	(void)sig;

	printf("\n\nReceived ctrl-c, exiting\n");
	serial.closeSerial();
	timeEndPeriod(1);

	signal(SIGINT, SIG_DFL);
	exit(0);
}

bool init()
{
	// trap ctrl-c
	signal(SIGINT, ex_program);
	printf("[ctrl-c]\n\n");

	// bump priority up so we get time from the sim
	SetPriorityClass(GetCurrentProcess(), HIGH_PRIORITY_CLASS);

	// ask for 1ms timer so sleeps are more precise
	timeBeginPeriod(1);


	int port;
	if (comPORT == -1) {
		
		int portList[32];
		int portCount = 32;
		port = serial.enumeratePorts(portList, &portCount);

		printf("Detected COM ports\t");
		for (int i = 0; i < portCount; i++) {
			printf("COM%i ", portList[i]);
		}
		printf("\n\n");

		// Try all detected com ports
		for (int i = 0; i < portCount; i++) {
			port = portList[i];
			printf("Connecting to COM%i\t", port);

			// CH340 driver fix: open at 9600 first to initialize the driver, then reopen at full speed
			serial.openSerial(port, CBR_9600);
			serial.closeSerial();
			// open serial
			if (serial.openSerial(port, CBR_115200))
			{
				printf("Connected\nDetecting hardware\t");

				bool matrix_gearFound = false;
				uint8_t detectCount = 0;
				while (!matrix_gearFound && detectCount < 30) {
					Sleep(100);
					detectCount++;
					char rxMSG[sizeof(rxDetect)] = "";
					DWORD rxLen = serial.readSerial(rxMSG, sizeof(rxDetect));
					if (rxLen > 1) {
						if (strcmp(rxMSG, rxDetect) == 0) {
							matrix_gearFound = true;
						}
					}
				}
				if (matrix_gearFound) {
					printf("%s\n", rxDetect);
					return true;
				}
				else {
					printf("Timeout\n");
					//return false;
				}
			}
			else {
				printf("Failed\n");
			}
		}
		printf("\nAuto detect failed\tDefine port manualy, -h for help\n");
		return false;
	}
	else {
		port = comPORT;
		printf("Connecting to COM%i\t", port);
		// CH340 driver fix: open at 9600 first to initialize the driver, then reopen at full speed
		serial.openSerial(port, CBR_9600);
		serial.closeSerial();
		if (serial.openSerial(port, CBR_115200))
		{
			printf("Connected\n");
			return true;
		}
		else {
			printf("Failed\n");
			return false;
		}

	}
}



void monitorConnectionStatus()
{
	// keep track of connection status
	if (firstConnect)
		printf("\nConnecting iRacing\t");

	bool isConnected = irsdkClient::instance().isConnected();
	static bool wasConnected = !isConnected;
	if(wasConnected != isConnected)
	{
		if (isConnected) {
			if (firstConnect){
				printf("Connected");
			}
			else {
				printf("\b\b\b\b\b\b\b\b\bConnected");
			}
		}
		else {
			if (firstConnect) {
				printf("Waiting  ");
			}
			else {
				printf("\b\b\b\b\b\b\b\b\bWaiting  ");
			}
			stop(1);
		}
		firstConnect = false;
		wasConnected = isConnected;
	}
}
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

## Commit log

2023-11-20 add Arduino sketch
2023-11-20 add housing stl files
    [iracing_matrix-base.stl, iracing_matrix-front.stl]
2026-05-29 Updated irsdk API files, Fix MinGW cross-compilation and add VS Code build setup
    [ir2ad.cpp, iracing_matrix.cpp]
2026-05-30 Fix CH340 driver error 31 by opening at 9600 before 115200
    [iracing_matrix.cpp]
